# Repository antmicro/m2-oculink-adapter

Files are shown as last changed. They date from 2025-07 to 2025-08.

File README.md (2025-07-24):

# M.2 to OCuLink Adapter

Copyright (c) 2025 [Antmicro](https://www.antmicro.com)



## Overview

This project includes PCB design files that define a simple M.2 (M-key) to OCuLink adapter.
It can be used for connecting the on-board PCIe M.2 slots with remote PCIe devices via OCuLink cables. 
This board has been designed to be compatible with Antmicro's [Jetson Orin Baseboard](https://github.com/antmicro/jetson-orin-baseboard).

If you plan to use it with other pieces of hardware, please inspect the schematics and connection diagrams beforehand. 
The PCB design files were prepared in KiCad 9.x.

## Key features

- Compatible with Antmicro's Jetson Orin Baseboard
- Exposes 4 lanes of PCIe via an OCuLink connector
- M.2 (M-key)
- OCuLink connector (Amphenol G14A421211112HR)
- Compatible with 2280, 2260, 2242 M.2 mechanical form factors

## License

This project is licensed under the [Apache-2.0](LICENSE) license.

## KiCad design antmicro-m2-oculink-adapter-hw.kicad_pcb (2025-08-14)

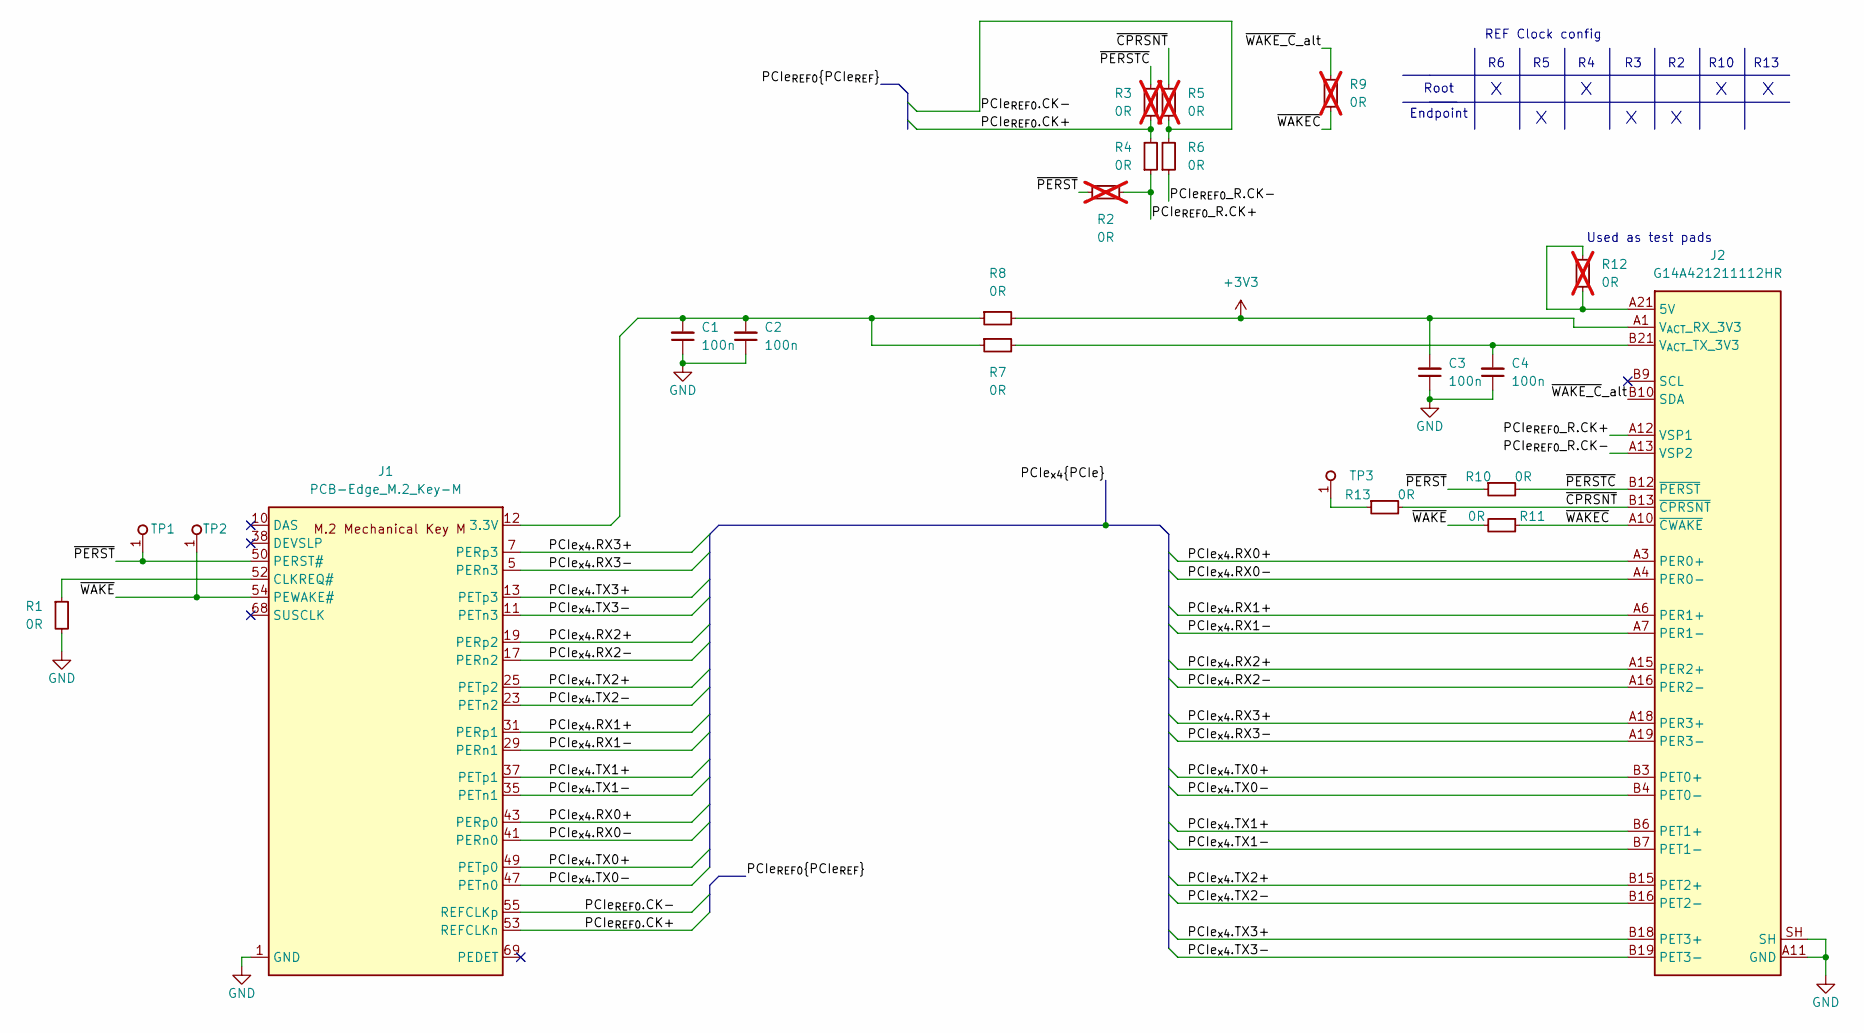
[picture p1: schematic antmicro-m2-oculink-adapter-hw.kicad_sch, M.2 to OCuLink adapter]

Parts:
C1, C2, C3, C4: C_100n_16V_X7R_0402; C_0402_1005Metric; Voltage 16V; MPN C0402C104J4RAC7411
J1: PCB-Edge_M.2_Key-M
J2: OCuLink_x4_Amphenol_G14A421211112HR; Amphenol_G14A421211112HR; MPN G14A421211112HR
R1, R7, R8, R11: R_0R_0402; R_0402_1005Metric; MPN ERJ2GE0R00X
R2, R3, R5, R9: R_0R_0201; R_0201; Tolerance 1%; MPN CR0201-FX-0R00GLF; not fitted
R4, R6, R10, R13: R_0R_0201; R_0201; Tolerance 1%; MPN CR0201-FX-0R00GLF
R12: R_0R_0402; R_0402_1005Metric; MPN ERJ2GE0R00X; not fitted
TP1, TP2: TP_1.5mm_SMD; TP_SMD_1.5mm
TP3: TP_1mm_SMD; TP_SMD_1mm

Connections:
+3V3: C3.2, J2.A1 (V_{ACT}_RX_3V3), R8.2
/PCIe_{REF0}.CK+: J1.53 (REFCLKn), R3.1, R4.2
/PCIe_{REF0}.CK-: J1.55 (REFCLKp), R5.1, R6.2
/PCIe_{REF0}_R.CK+: J2.A12 (VSP1), R2.1, R4.1
/PCIe_{REF0}_R.CK-: J2.A13 (VSP2), R6.1
/PCIe_{x4}.RX0+: J1.43 (PERp0), J2.A3 (PER0+)
/PCIe_{x4}.RX0-: J1.41 (PERn0), J2.A4 (PER0-)
/PCIe_{x4}.RX1+: J1.31 (PERp1), J2.A6 (PER1+)
/PCIe_{x4}.RX1-: J1.29 (PERn1), J2.A7 (PER1-)
/PCIe_{x4}.RX2+: J1.19 (PERp2), J2.A15 (PER2+)
/PCIe_{x4}.RX2-: J1.17 (PERn2), J2.A16 (PER2-)
/PCIe_{x4}.RX3+: J1.7 (PERp3), J2.A18 (PER3+)
/PCIe_{x4}.RX3-: J1.5 (PERn3), J2.A19 (PER3-)
/PCIe_{x4}.TX0+: J1.49 (PETp0), J2.B3 (PET0+)
/PCIe_{x4}.TX0-: J1.47 (PETn0), J2.B4 (PET0-)
/PCIe_{x4}.TX1+: J1.37 (PETp1), J2.B6 (PET1+)
/PCIe_{x4}.TX1-: J1.35 (PETn1), J2.B7 (PET1-)
/PCIe_{x4}.TX2+: J1.25 (PETp2), J2.B15 (PET2+)
/PCIe_{x4}.TX2-: J1.23 (PETn2), J2.B16 (PET2-)
/PCIe_{x4}.TX3+: J1.13 (PETp3), J2.B18 (PET3+)
/PCIe_{x4}.TX3-: J1.11 (PETn3), J2.B19 (PET3-)
/~CPRSNT: J2.B13 (~CPRSNT), R5.2, R13.2
/~PERSTC: J2.B12 (~PERST), R3.2, R10.2
/~PERST: J1.50 (PERST#), R2.2, R10.1, TP1.1
/~WAKEC: J2.A10 (~CWAKE), R9.1, R11.1
/~WAKE_C_alt: J2.B10 (SDA), R9.2
/~WAKE: J1.54 (PEWAKE#), R11.2, TP2.1
GND: C1.1, C2.1, C3.1, C4.1, J1.1 (GND), J1.3 (GND), J1.9 (GND), J1.15 (GND), J1.21 (GND), J1.27 (GND), J1.33 (GND), J1.39 (GND), J1.45 (GND), J1.51 (GND), J1.57 (GND), J1.71 (GND), J1.73 (GND), J1.75 (GND), J2.A2 (GND), J2.A5 (GND), J2.A8 (GND), J2.A11 (GND), J2.A14 (GND), J2.A17 (GND), J2.A20 (GND), J2.B2 (GND), J2.B5 (GND), J2.B8 (GND), J2.B11 (GND), J2.B14 (GND), J2.B17 (GND), J2.B20 (GND), J2.SH, R1.2
unnamed: C1.2, C2.2, J1.2 (3.3V), J1.4 (3.3V), J1.12 (3.3V), J1.14 (3.3V), J1.16 (3.3V), J1.18 (3.3V), J1.70 (3.3V), J1.72 (3.3V), J1.74 (3.3V), R7.1, R8.1
unnamed: J1.52 (CLKREQ#), R1.1
unnamed: J2.A21 (5V), J2.B1 (5V), R12.1, R12.2
unnamed: C4.2, J2.B21 (V_{ACT}_TX_3V3), R7.2
unnamed: R13.1, TP3.1

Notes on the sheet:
REF Clock config
Endpoint
Root
Used as test pads
R13
R10

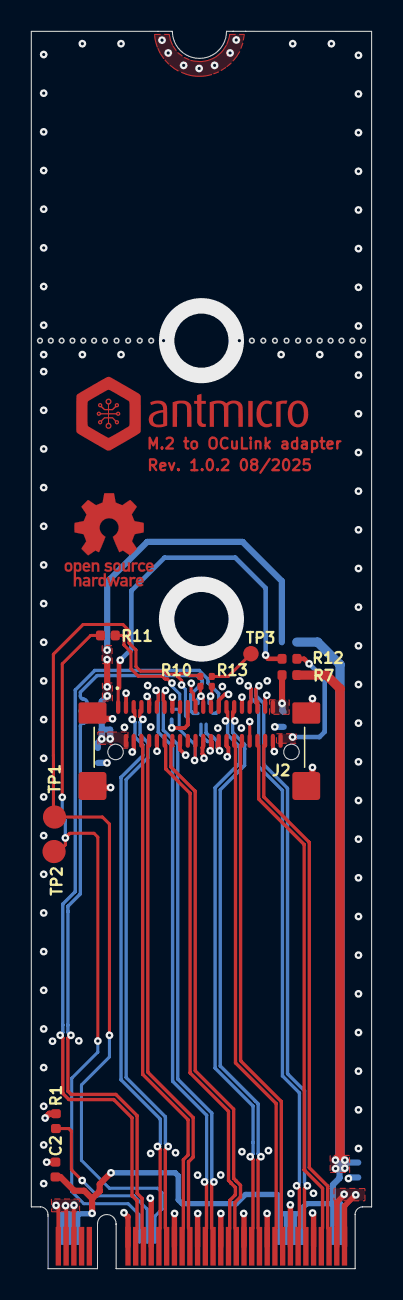
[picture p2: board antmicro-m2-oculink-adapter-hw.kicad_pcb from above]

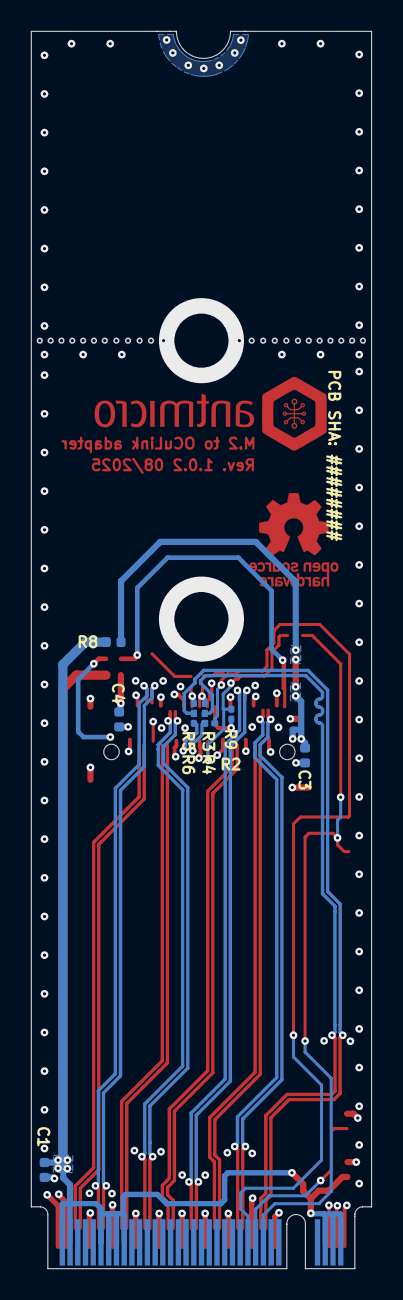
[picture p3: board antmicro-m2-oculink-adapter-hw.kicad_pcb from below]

Board: 4 copper layers, 22.0 x 80.0 mm, 22 parts (10 on the bottom side), 33 nets.

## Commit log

2025-07-09 [#79281] Inital commit
    [antmicro-oculink-m2-adapter-hw.kicad_pcb, antmicro-oculink-m2-adapter-hw.kicad_sch]
2025-07-24 [#79281] Add ci.yml, initial connector placement
    [antmicro-oculink-m2-adapter-hw.kicad_pcb]
2025-07-24 [#79281] Fix lane polarity
    [antmicro-oculink-m2-adapter-hw.kicad_sch]
2025-07-24 [#79281] Connector placement and PCIe routing
    [antmicro-oculink-m2-adapter-hw.kicad_pcb]
2025-07-24 [#79281] Clean up gnd vias and pcie routing
    [antmicro-oculink-m2-adapter-hw.kicad_pcb]
2025-07-24 [#79281] Add .gitignore and remove kicad_prl file
2025-07-24 [#79281] Rename files, Fix net class naming, Undo crossover on PCIe lanes, change OCulink symbol to host side version
    [antmicro-m2-oculink-adapter-hw.kicad_pcb, antmicro-m2-oculink-adapter-hw.kicad_sch]
2025-07-24 [#79281] Remove unnecessary text on schematic
    [antmicro-m2-oculink-adapter-hw.kicad_sch]
2025-07-24 [#79281] Remove old files
    [antmicro-oculink-m2-adapter-hw.kicad_pcb, antmicro-oculink-m2-adapter-hw.kicad_sch]
2025-07-24 [#79281] Place 0R resistors and test points
    [antmicro-m2-oculink-adapter-hw.kicad_pcb]
2025-07-24 [#79281] Change 0R sizing, add OSHW logo, route 3.3V rail and control signals
    [antmicro-m2-oculink-adapter-hw.kicad_pcb, antmicro-m2-oculink-adapter-hw.kicad_sch]
2025-07-24 [#79281] Fix schematic annotation
    [antmicro-m2-oculink-adapter-hw.kicad_sch]
2025-07-24 [#80280] Add mouse bites
    [antmicro-m2-oculink-adapter-hw.kicad_pcb]
2025-07-24 [#80280] Round diff pairs. Move logo to 2 segment and make more room for the OCulink cable
    [antmicro-m2-oculink-adapter-hw.kicad_pcb]
2025-07-24 [#80280] Fix DRC
    [antmicro-m2-oculink-adapter-hw.kicad_pcb, antmicro-m2-oculink-adapter-hw.kicad_sch]
2025-07-24 [#80280] CI test
    [antmicro-m2-oculink-adapter-hw.kicad_pcb]
2025-07-24 [#80280] Rename edge drill hole, fix drc
    [antmicro-m2-oculink-adapter-hw.kicad_pcb]
2025-07-24 [#80280] Modify edge drill hole to use pad instead of filled polygon
    [antmicro-m2-oculink-adapter-hw.kicad_pcb]
2025-07-24 [#80280] Workaround kicad bug
    [antmicro-m2-oculink-adapter-hw.kicad_pcb]
2025-07-24 [#80280] Move edge cuts from footprints
    [antmicro-m2-oculink-adapter-hw.kicad_pcb]
2025-07-24 [#80280] Add PCB SHA string
    [antmicro-m2-oculink-adapter-hw.kicad_pcb]
2025-07-24 [#80280] Add User 9 layer
    [antmicro-m2-oculink-adapter-hw.kicad_pcb]
2025-07-24 [#80280] Cleanup tracks
    [antmicro-m2-oculink-adapter-hw.kicad_pcb]
2025-07-24 [#80280] Clean up tracks, change gnd cutout size, fix drc errors, add more vias, move antmicro logo, change text size
    [antmicro-m2-oculink-adapter-hw.kicad_pcb]
2025-07-24 [#80747] Clean up tracks
    [antmicro-m2-oculink-adapter-hw.kicad_pcb]
2025-07-24 [#80747] Replace edge drill footprint
    [antmicro-m2-oculink-adapter-hw.kicad_pcb]
2025-07-24 [#80747] change antmicro logo and correct date format
    [antmicro-m2-oculink-adapter-hw.kicad_pcb]
2025-07-24 [#80747] Fix DRC
    [antmicro-m2-oculink-adapter-hw.kicad_pcb]
2025-07-24 [#80747] Remove soldermask from drill opening
    [antmicro-m2-oculink-adapter-hw.kicad_pcb]
2025-07-24 [#80747] Change drill hole size to 3.5mm
    [antmicro-m2-oculink-adapter-hw.kicad_pcb]
2025-07-24 [#80747] Kmake bug workaround
    [antmicro-m2-oculink-adapter-hw.kicad_pcb]
2025-07-25 [#80997] Fix stack-up
    [antmicro-m2-oculink-adapter-hw.kicad_pcb]
2025-07-28 [#81030] Rotate sha
    [antmicro-m2-oculink-adapter-hw.kicad_pcb]
2025-07-28 [#81030] Change OCulink connector pad size to 0.28mm
    [antmicro-m2-oculink-adapter-hw.kicad_pcb]
2025-07-31 [#81131] Change resistor, testpoint sizing. Add 0R to 3V3 and ~CWAKE
    [antmicro-m2-oculink-adapter-hw.kicad_sch]
2025-07-31 [#81131] Add 0R selector for refclk
    [antmicro-m2-oculink-adapter-hw.kicad_pcb, antmicro-m2-oculink-adapter-hw.kicad_sch]
2025-07-31 [#81131] Cleanup tracks
    [antmicro-m2-oculink-adapter-hw.kicad_pcb]
2025-07-31 [#81131] Clean up drc
    [antmicro-m2-oculink-adapter-hw.kicad_pcb, antmicro-m2-oculink-adapter-hw.kicad_sch]
2025-07-31 [#81131] Fix meander add gnd connections
    [antmicro-m2-oculink-adapter-hw.kicad_pcb]
2025-07-31 [#81131] Fix vias, zones
    [antmicro-m2-oculink-adapter-hw.kicad_pcb]
2025-07-31 [#81131] Fix schematic 3V3
    [antmicro-m2-oculink-adapter-hw.kicad_pcb, antmicro-m2-oculink-adapter-hw.kicad_sch]
2025-07-31 [#81131] Clean drc
    [antmicro-m2-oculink-adapter-hw.kicad_pcb, antmicro-m2-oculink-adapter-hw.kicad_sch]
2025-07-31 [#81131] Clean-up tracks, shorten stubs, relocate R1, align silkscreen
    [antmicro-m2-oculink-adapter-hw.kicad_pcb, antmicro-m2-oculink-adapter-hw.kicad_sch]
2025-07-31 [#81131] Add 0R on 5V, Clean drc
    [antmicro-m2-oculink-adapter-hw.kicad_pcb, antmicro-m2-oculink-adapter-hw.kicad_sch]
2025-08-01 [#81131] Increase silkscreen spacing, add gnd cutouts to vias, increase distance drill to traces, remove solder mask from m.2 connector
    [antmicro-m2-oculink-adapter-hw.kicad_pcb, antmicro-m2-oculink-adapter-hw.kicad_sch]
2025-08-01 [#81131] remove silkscreen from revision, add testpoint to CPRSNT
    [antmicro-m2-oculink-adapter-hw.kicad_pcb, antmicro-m2-oculink-adapter-hw.kicad_sch]
2025-08-01 [#81131] Kmake bug workaround
    [antmicro-m2-oculink-adapter-hw.kicad_pcb]
2025-08-01 [#81131] Remove plane, adjust silkscreen
    [antmicro-m2-oculink-adapter-hw.kicad_pcb]
2025-08-01 [#81131] Align silkscreen
    [antmicro-m2-oculink-adapter-hw.kicad_pcb]
2025-08-12 [#81086] Change mousebite size to 0.4mm diameter
    [antmicro-m2-oculink-adapter-hw.kicad_pcb]
2025-08-14 [#81086] Remove unnecesary GND cutout, bump revision
    [antmicro-m2-oculink-adapter-hw.kicad_pcb, antmicro-m2-oculink-adapter-hw.kicad_sch]

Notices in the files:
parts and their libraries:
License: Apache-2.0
